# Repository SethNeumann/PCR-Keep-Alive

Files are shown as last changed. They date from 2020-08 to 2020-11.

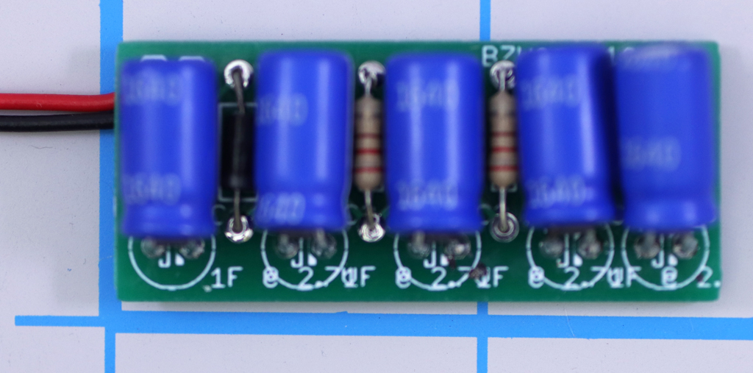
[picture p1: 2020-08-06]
PCR-Keep-Alive-Graphic.png

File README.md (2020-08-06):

# REPO NAME: EagleTemplate-new
## License: Creative Commons Attribution-NonCommercial-ShareAlike

A Keep-Alive is a large capacitor that will keep a DCC-equipped locomotive running for a few seconds in the absence of power to get over dirty track or a dead frog.  They can be used with most decoders.
Phil mentioned using a circuit found on the web instead of expensive offerings from decoder manufacturers
He started with something like https://www.dccguy.com/?tag=keep-alive by Dr. Larry Puckett (thanks Larry!)

We made some component changes:
Discharge Bypass Diode to Schottky 1N5819 (lower forward drop, less power)
Zener diode to 13V 1W 1N5243B 
Instead of 1/2W 100 ohm, used 2x220 ohm at 1/4W to save height and use a more available component

Note using a KA, other than the decoder manufacturers’, may void the decoder warranty

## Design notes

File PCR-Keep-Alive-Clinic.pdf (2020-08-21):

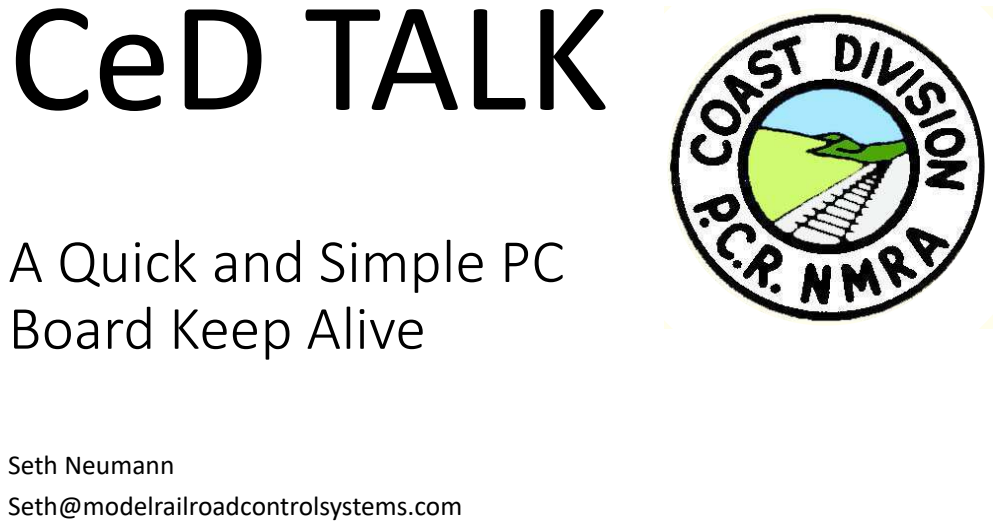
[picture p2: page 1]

A Quick and Simple PC
Board Keep Alive

Seth Neumann
Seth@modelrailroadcontrolsystems.com

# Why make a Keep-Alive board?

- A Keep-Alive is a large capacitor that will keep a DCC-equipped locomotive running for a few seconds in the absence of power to get over dirty track or a dead frog. They can be used with most decoders. • Phil mentioned using a circuit found on the web instead of expensive offerings from decoder manufacturers
- He started with something like https://www.dccguy.com/?tag=keep-alive by Dr. Larry Puckett (thanks Larry!)
- Note using a KA, other than the decoder manufacturers’, may void the decoder warranty
8/19/2020 | PCR Keep Alive for Coast Meet up August 8, 2020 | 2

# Pros and Cons of a KA like this

## - Good:

## - Inexpensive – about $8.00 in parts - Easy to assemble in various physical configurations

## - Not so Good:

## - Space wiring is hassle and is prone to coming apart at inopportune times (such as when the shell is tightened down)

## - Solution:

## - Use low cost circuit board to hold everything together

- Less flexibility in size but it can fit within an HO EMD shell.
8/19/2020 | PCR Keep Alive for Coast Meet up August 8, 2020 | 3

# My implementation

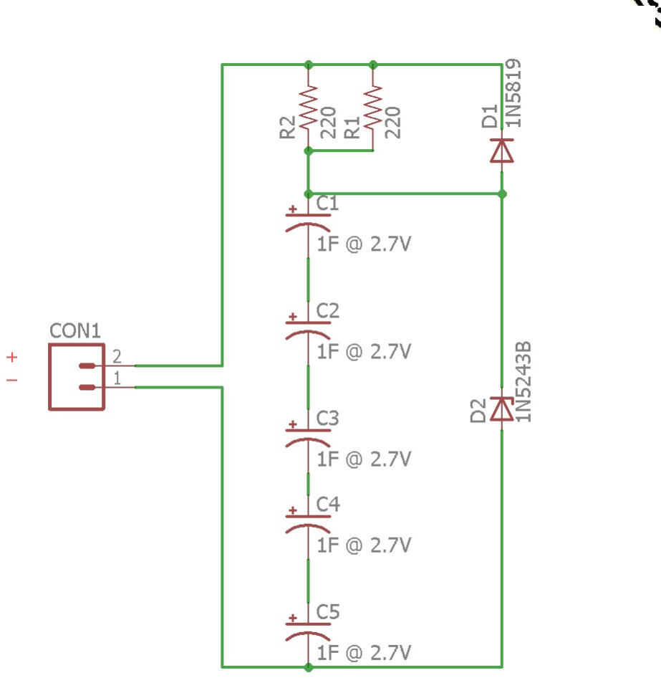
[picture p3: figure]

## - Discussed the application with DCC gurus “the Marks Brothers” - Made some component changes:

## - Discharge Bypass Diode to Schottky 1N5819 (lower forward drop, less power dissipated, so smaller) - Changed Zener diode to 13V 1W 1N5243B - smaller - I used 2x220 ohm at 1/4W instead of Instead of 1/2W 100 ohm to save height and use a more available component

# Prototype with Guy Cantwell

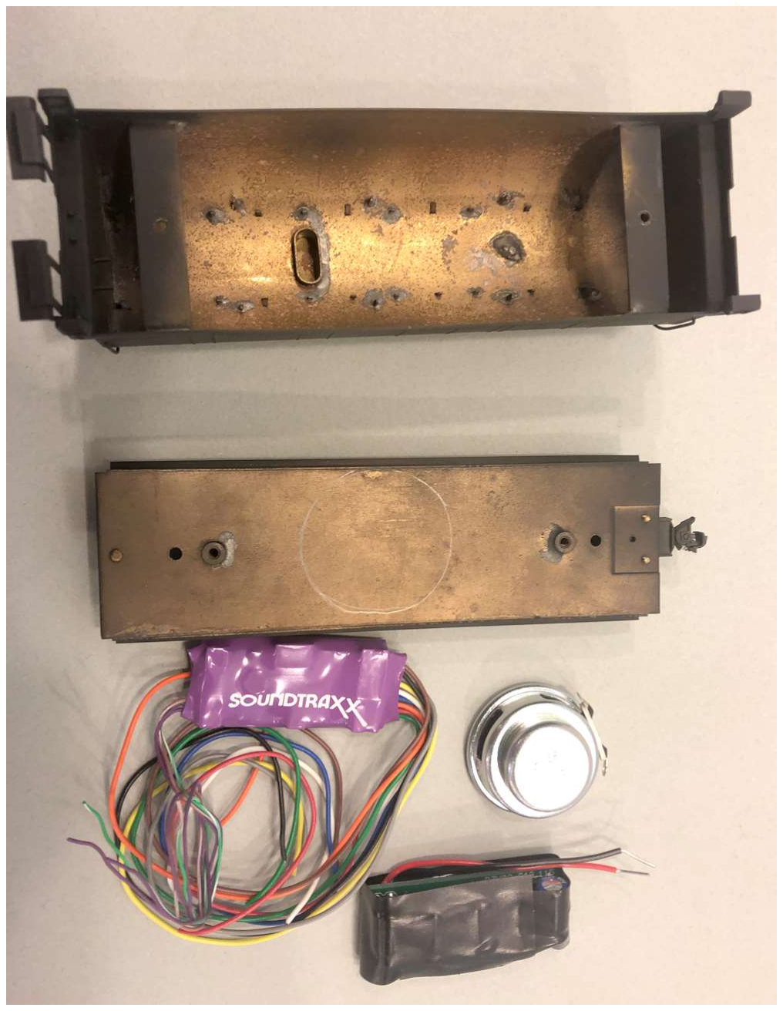
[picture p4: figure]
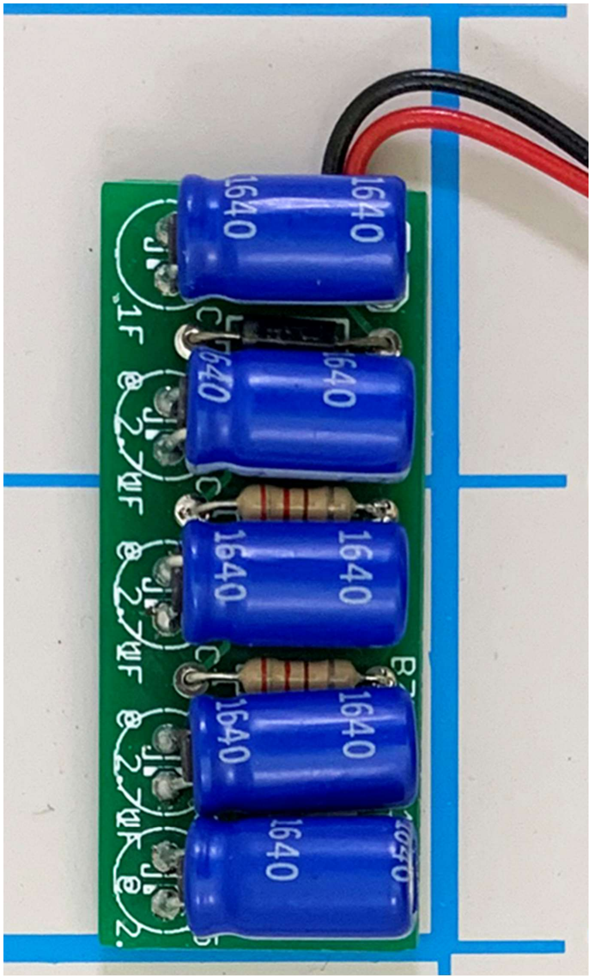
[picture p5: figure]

8/19/2020 | PCR Keep Alive for Coast Meet up August 8, 2020 | 5

.710” wide (17.5 mm)
1.650” long (42mm)
.400” thick (10 mm) –

# Bare Board

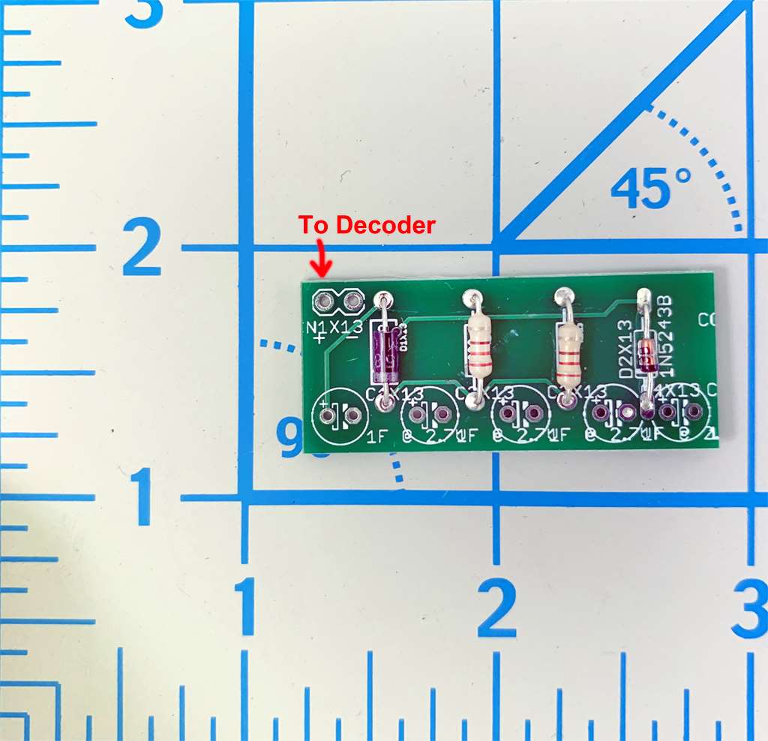
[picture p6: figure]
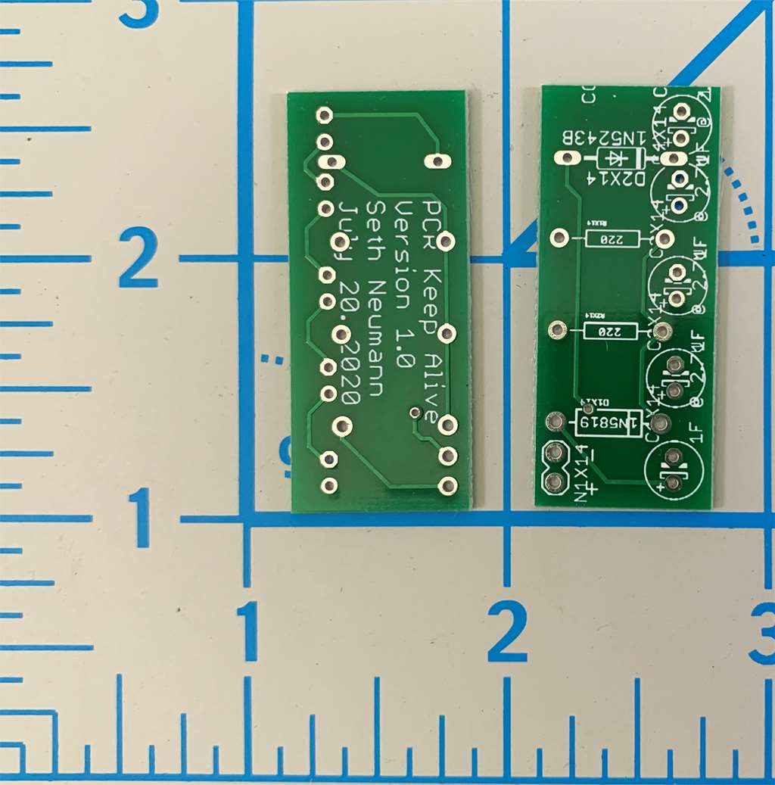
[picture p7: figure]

8/20/2020 | PCR Keep Alive for Coast Meet up August 8, 2020 | 6
Top and Bottom | Diodes and Resistor stuffed

# How does it fit?

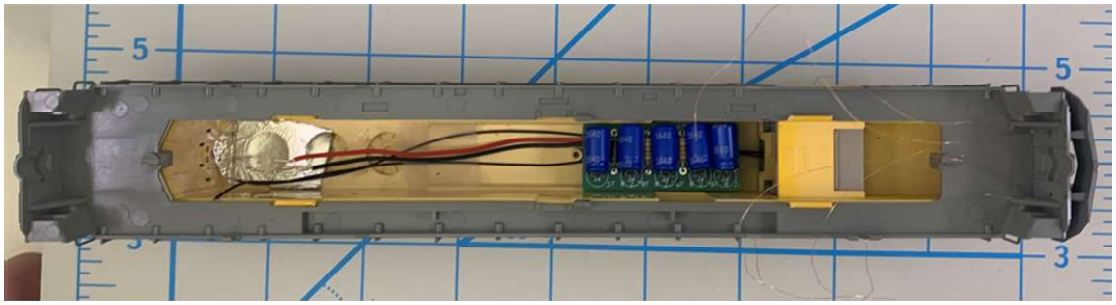
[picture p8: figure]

8/19/2020 | PCR Keep Alive for Coast Meet up August 8, 2020 | 7

## PCR-Keep-Alive in Athearn SD40-2 shell

# Guy Cantwell’s Steam Installation

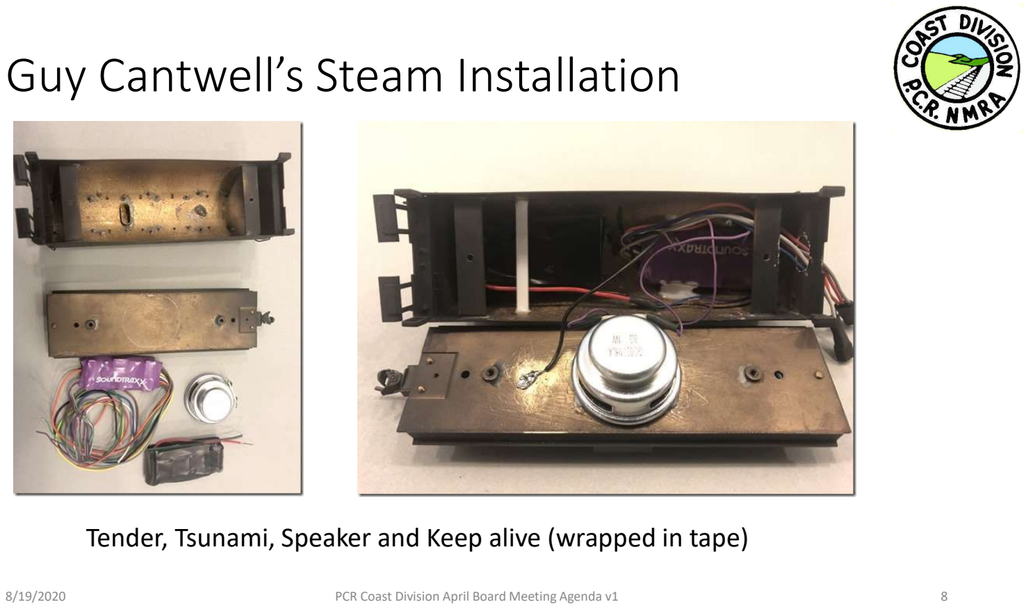
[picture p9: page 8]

8/19/2020 | PCR Coast Division April Board Meeting Agenda v1 | 8

## Tender, Tsunami, Speaker and Keep alive (wrapped in tape)

# Bill of Materials – 1 Unit

Quantity | Description | Digikey P/N | Unit | Ext’d
1 | Printed Circuit Board (panel of 10) | MRCS | $5.00 | $0.50
5 | AVX 1F 2.7V Super Capacitor | 478-10010-ND | $1.26 | $6.30
1 | 1N5819 1W Schottky Diode | 497-6610-1-ND | $0.30 | $0.30
1 | 1N5243B 13V 1W Zener | 1N5243BTRFSCT-ND | $0.14 | $0.14
2 | 220 ohm @ ¼ W resistor | CF14JT220RCT-ND | $0.10 | $0.20
Total for 1 unit | $7.44
8/19/2020 | 9

Plus sales tax, shipping, tariff surcharges etc, ~$20.00

You can purchase this BOM from Digikey at https://www.digikey.com/short/z5229d

# Bill of Materials – 10 Units

8/19/2020 | PCR Keep Alive for Coast Meet up August 8, 2020 | 10
Quantity | Description | Digikey P/N | Unit | Ext’d
10 | Printed Circuit Board (panel of 10) | MRCS | $5.00 | $5.00
50 | AVX 1F 2.7V Super Capacitor | 478-10010-ND | $1.09 | 54.60
10 | 1N5819 1W Schottky Diode | 497-6610-1-ND | $0.12 | $1.23
10 | 1N5243B 13V 1W Zener | 1N5243BTRFSCT-ND | $0.25 | $2.47
25 | 220 ohm @ ¼ W resistor | CF14JT220RCT-ND | $0.03 | $0.70
Total for 10 units | $64.00

Plus sales tax, shipping, tariff surcharges etc. ~ $13.00

You can purchase this BOM from Digikey at https://www.digikey.com/short/z52wpf

# Options to Purchase

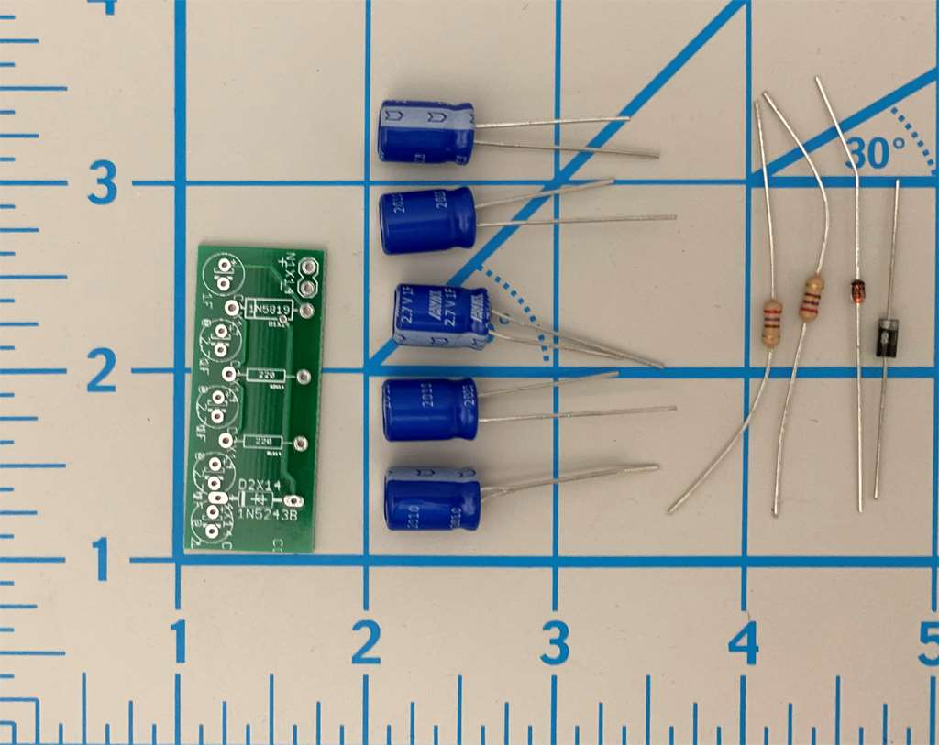
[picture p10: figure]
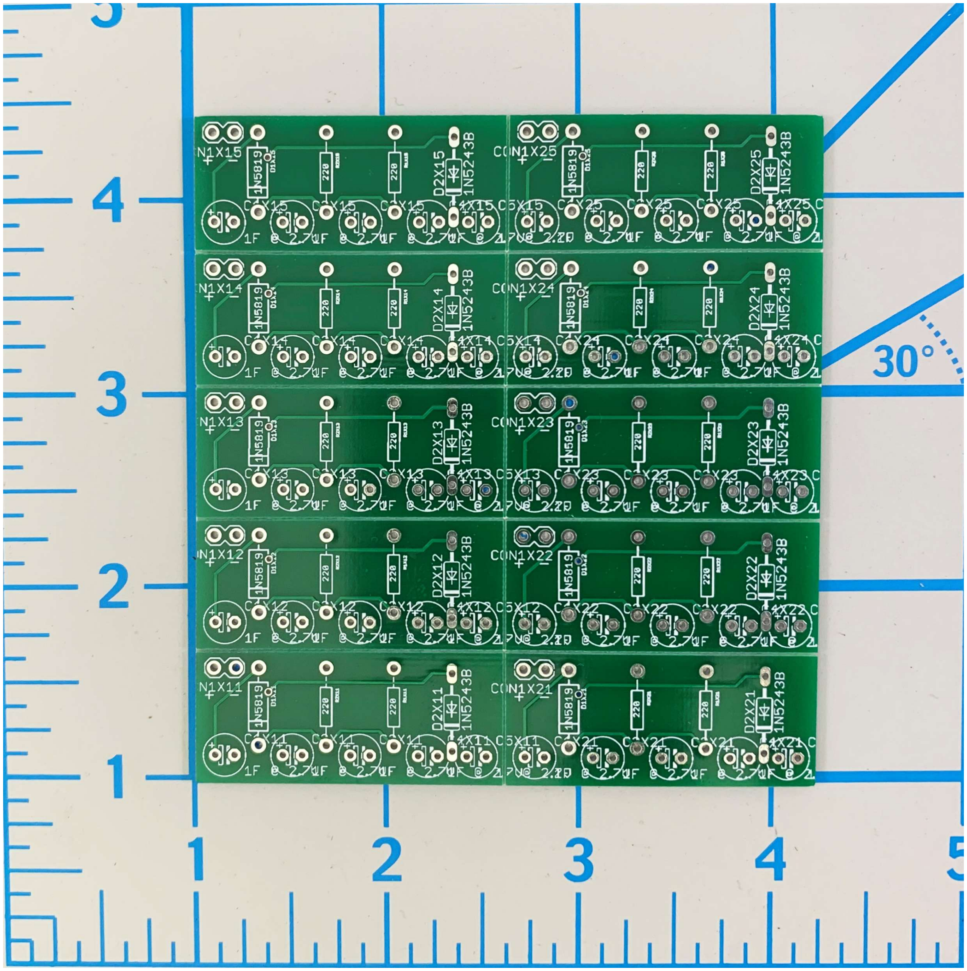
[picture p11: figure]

8/20/2020 | PCR Coast Division April Board Meeting Agenda v1 | 11
Panel of 10 - $5.00 | Kit for 1 - $9.95

# References and links

## - EAGLE CAD Files on my GitHub https://github.com/SethNeumann/PCR-Keep-Alive - MRCS Product Page for board https://www.modelrailroadcontrolsystems.com/pcr-keep-alive-panel-

of-10/

## - Larry Puckett’s Article like https://www.dccguy.com/?tag=keep-alive

8/19/2020 | PCR Keep Alive for Coast Meet up August 8, 2020 | 12

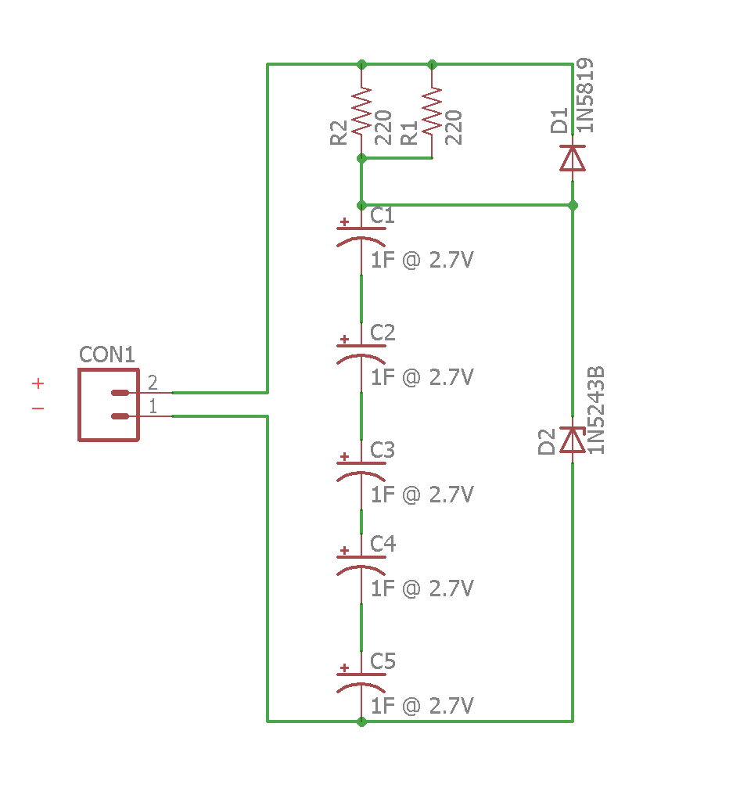
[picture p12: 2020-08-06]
PCR-KA-V2.png

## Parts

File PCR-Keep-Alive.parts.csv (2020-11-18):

# name | smd? | value | package | component | x | y | angle | YXAngle |  |  | Vendor | Part | Unit | Leads
PCB |  |  |  | PCR-Keep-Alive |  |  |  |  |  |  |  |  | 0.10
C1 | PTH | 1F @ 2.7V | E2 | 6-May | 1f @ 2.7v-e2 | 6-May | 0 | 0 | 0 | 90 | Digikey | ?SCCR12B105PRB | 1.26 | 2
C2 | PTH | 1F @ 2.7V | E2 | 6-May | 1f @ 2.7v-e2 | 6-May | 0 | 0 | 0 | 90 | Digikey | ?SCCR12B105PRB | 1.26
C3 | PTH | 1F @ 2.7V | E2 | 6-May | 1f @ 2.7v-e2 | 6-May | 0 | 0 | 0 | 90 | Digikey | ?SCCR12B105PRB | 1.26
C4 | PTH | 1F @ 2.7V | E2 | 6-May | 1f @ 2.7v-e2 | 6-May | 0 | 0 | 0 | 90 | Digikey | ?SCCR12B105PRB | 1.26
C5 | PTH | 1F @ 2.7V | E2 | 6-May | 1f @ 2.7v-e2 | 6-May | 0 | 0 | 0 | 90 | Digikey | ?SCCR12B105PRB | 1.26
CON1 | PTH |  | 1X02_LOCK | -1x02_lock | 0 | 0 | 180 | -90
D1 | PTH | 1N5819 | DIODE-1N4001 | 1n5819-diode-1n4001 | 0 | 0 | 90 | 0 |  |  | Digikey | 497-6610-1-ND | 0.21
D2 | PTH | 1N5243B | DO35Z10 | 1n5243b-do35z10 | 0 | 0 | 90 | 0 |  |  | Digikey | 1N5243BTRFSTR-ND | 0.13
R1 | PTH | 220 | AXIAL-0.4-RES | 220 -axial-0.4-res | 0 | 0 | 270 | 180 |  |  | Any |  | 0.04
R2 | PTH | 220 | AXIAL-0.4-RES | 220 -axial-0.4-res | 0 | 0 | 270 | 180 |  |  |  |  | 0.04
 |  |  |  |  |  |  |  |  |  |  |  |  | $6.82

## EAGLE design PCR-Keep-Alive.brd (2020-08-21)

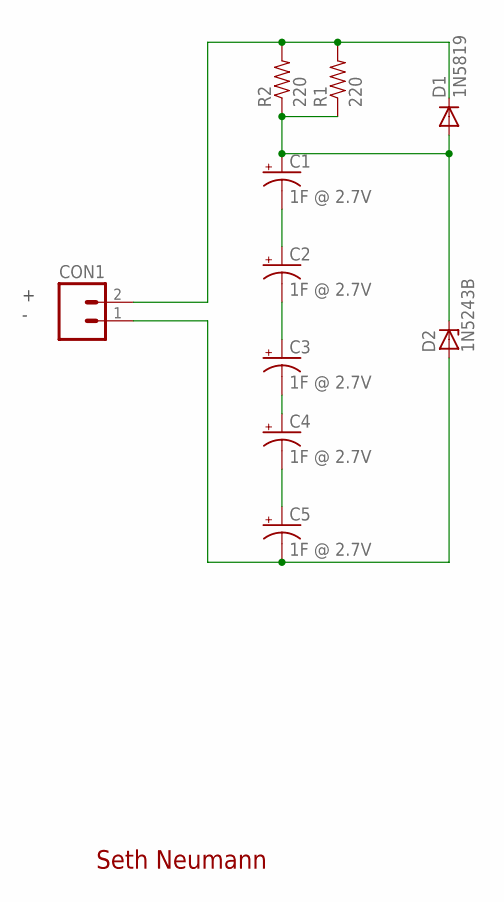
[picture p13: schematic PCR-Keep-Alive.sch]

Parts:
C1, C2, C3, C4, C5: 1F @ 2.7V; E2,5-6
CON1: CONNECTOR-M021X02-LOCK; 1X02_LOCK
D1: 1N5819; DIODE-1N4001
D2: 1N5243B; DO35Z10
R1, R2: 220; AXIAL-0.4-RES

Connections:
unnamed: C1.-, C2.+
unnamed: C2.-, C3.+
unnamed: C3.-, C4.+
unnamed: C4.-, C5.+
unnamed: C1.+, D1.A, D2.C, R1.P$1 (1), R2.P$1 (1)
NEG: C5.-, CON1.1 (A), D2.A
POS: CON1.2 (B), D1.C, R1.P$2 (2), R2.P$2 (2)

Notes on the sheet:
Seth Neumann
+ -

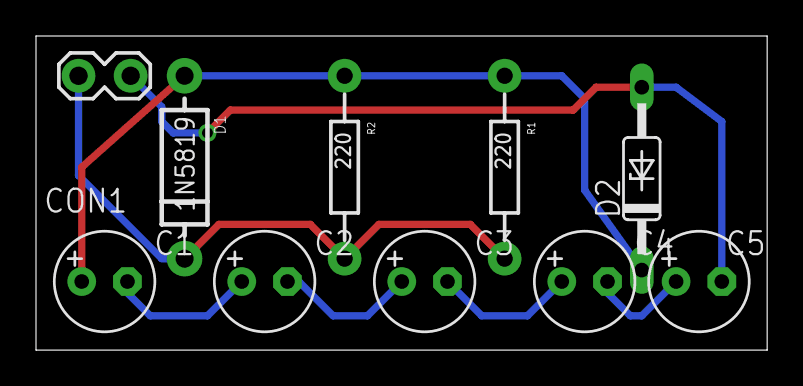
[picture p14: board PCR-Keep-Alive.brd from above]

Board: 2 copper layers, 40.6 x 17.4 mm, 10 parts (0 on the bottom side), 7 nets.

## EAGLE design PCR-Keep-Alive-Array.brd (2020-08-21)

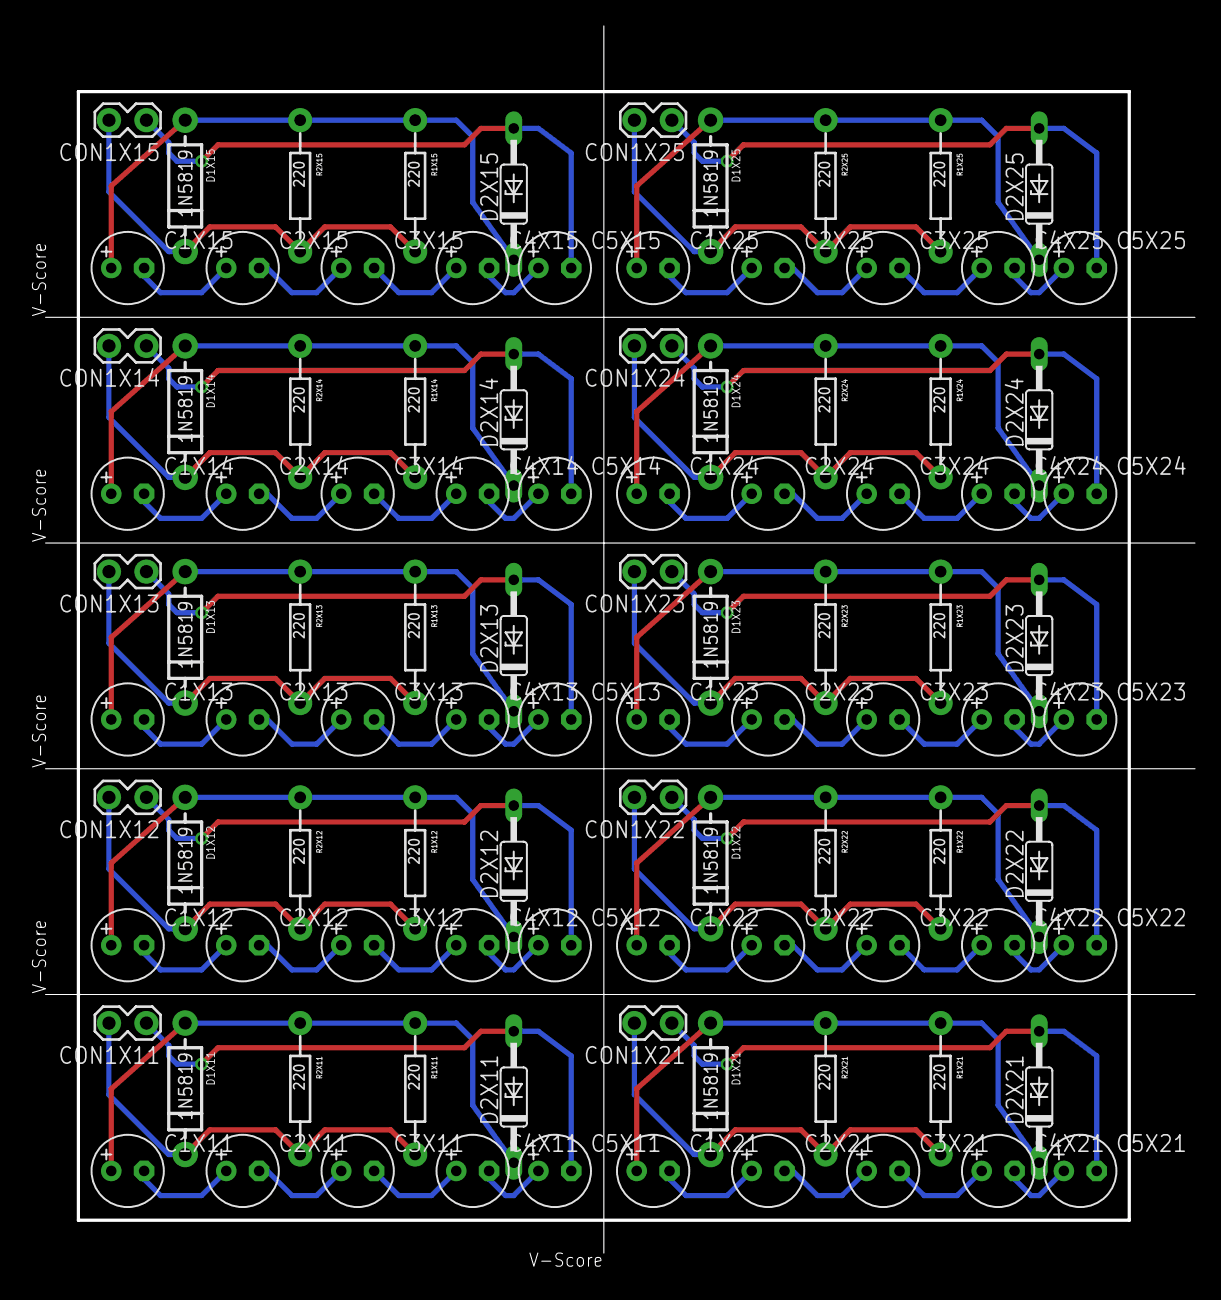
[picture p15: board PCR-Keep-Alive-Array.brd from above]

Board: 2 copper layers, 88.9 x 94.9 mm, 100 parts (0 on the bottom side), 70 nets.

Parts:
C1X11, C1X12, C1X13, C1X14, C1X15, C1X21, C1X22, C1X23, C1X24, C1X25, C2X11, C2X12, C2X13, C2X14, C2X15, C2X21, C2X22, C2X23, C2X24, C2X25, C3X11, C3X12, C3X13, C3X14, C3X15, C3X21, C3X22, C3X23, C3X24, C3X25, C4X11, C4X12, C4X13, C4X14, C4X15, C4X21, C4X22, C4X23, C4X24, C4X25, C5X11, C5X12, C5X13, C5X14, C5X15, C5X21, C5X22, C5X23, C5X24, C5X25: 1F @ 2.7V; E2,5-6
CON1X11, CON1X12, CON1X13, CON1X14, CON1X15, CON1X21, CON1X22, CON1X23, CON1X24, CON1X25: 1X02_LOCK
D1X11, D1X12, D1X13, D1X14, D1X15, D1X21, D1X22, D1X23, D1X24, D1X25: 1N5819; DIODE-1N4001
D2X11, D2X12, D2X13, D2X14, D2X15, D2X21, D2X22, D2X23, D2X24, D2X25: 1N5243B; DO35Z10
R1X11, R1X12, R1X13, R1X14, R1X15, R1X21, R1X22, R1X23, R1X24, R1X25, R2X11, R2X12, R2X13, R2X14, R2X15, R2X21, R2X22, R2X23, R2X24, R2X25: 220; AXIAL-0.4-RES

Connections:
unnamed: C1X11.-, C2X11.+
unnamed: C1X12.-, C2X12.+
unnamed: C1X13.-, C2X13.+
unnamed: C1X14.-, C2X14.+
unnamed: C1X15.-, C2X15.+
unnamed: C1X21.-, C2X21.+
unnamed: C1X22.-, C2X22.+
unnamed: C1X23.-, C2X23.+
unnamed: C1X24.-, C2X24.+
unnamed: C1X25.-, C2X25.+
unnamed: C2X11.-, C3X11.+
unnamed: C2X12.-, C3X12.+
unnamed: C2X13.-, C3X13.+
unnamed: C2X14.-, C3X14.+
unnamed: C2X15.-, C3X15.+
unnamed: C2X21.-, C3X21.+
unnamed: C2X22.-, C3X22.+
unnamed: C2X23.-, C3X23.+
unnamed: C2X24.-, C3X24.+
unnamed: C2X25.-, C3X25.+
unnamed: C3X11.-, C4X11.+
unnamed: C3X12.-, C4X12.+
unnamed: C3X13.-, C4X13.+
unnamed: C3X14.-, C4X14.+
unnamed: C3X15.-, C4X15.+
unnamed: C3X21.-, C4X21.+
unnamed: C3X22.-, C4X22.+
unnamed: C3X23.-, C4X23.+
unnamed: C3X24.-, C4X24.+
unnamed: C3X25.-, C4X25.+
unnamed: C4X11.-, C5X11.+
unnamed: C4X12.-, C5X12.+
unnamed: C4X13.-, C5X13.+
unnamed: C4X14.-, C5X14.+
unnamed: C4X15.-, C5X15.+
unnamed: C4X21.-, C5X21.+
unnamed: C4X22.-, C5X22.+
unnamed: C4X23.-, C5X23.+
unnamed: C4X24.-, C5X24.+
unnamed: C4X25.-, C5X25.+
unnamed: C1X11.+, D1X11.A, D2X11.C, R1X11.P$1, R2X11.P$1
unnamed: C1X12.+, D1X12.A, D2X12.C, R1X12.P$1, R2X12.P$1
unnamed: C1X13.+, D1X13.A, D2X13.C, R1X13.P$1, R2X13.P$1
unnamed: C1X14.+, D1X14.A, D2X14.C, R1X14.P$1, R2X14.P$1
unnamed: C1X15.+, D1X15.A, D2X15.C, R1X15.P$1, R2X15.P$1
unnamed: C1X21.+, D1X21.A, D2X21.C, R1X21.P$1, R2X21.P$1
unnamed: C1X22.+, D1X22.A, D2X22.C, R1X22.P$1, R2X22.P$1
unnamed: C1X23.+, D1X23.A, D2X23.C, R1X23.P$1, R2X23.P$1
unnamed: C1X24.+, D1X24.A, D2X24.C, R1X24.P$1, R2X24.P$1
unnamed: C1X25.+, D1X25.A, D2X25.C, R1X25.P$1, R2X25.P$1
NEGX11: C5X11.-, CON1X11.1, D2X11.A
NEGX12: C5X12.-, CON1X12.1, D2X12.A
NEGX13: C5X13.-, CON1X13.1, D2X13.A
NEGX14: C5X14.-, CON1X14.1, D2X14.A
NEGX15: C5X15.-, CON1X15.1, D2X15.A
NEGX21: C5X21.-, CON1X21.1, D2X21.A
NEGX22: C5X22.-, CON1X22.1, D2X22.A
NEGX23: C5X23.-, CON1X23.1, D2X23.A
NEGX24: C5X24.-, CON1X24.1, D2X24.A
NEGX25: C5X25.-, CON1X25.1, D2X25.A
POSX11: CON1X11.2, D1X11.C, R1X11.P$2, R2X11.P$2
POSX12: CON1X12.2, D1X12.C, R1X12.P$2, R2X12.P$2
POSX13: CON1X13.2, D1X13.C, R1X13.P$2, R2X13.P$2
POSX14: CON1X14.2, D1X14.C, R1X14.P$2, R2X14.P$2
POSX15: CON1X15.2, D1X15.C, R1X15.P$2, R2X15.P$2
POSX21: CON1X21.2, D1X21.C, R1X21.P$2, R2X21.P$2
POSX22: CON1X22.2, D1X22.C, R1X22.P$2, R2X22.P$2
POSX23: CON1X23.2, D1X23.C, R1X23.P$2, R2X23.P$2
POSX24: CON1X24.2, D1X24.C, R1X24.P$2, R2X24.P$2
POSX25: CON1X25.2, D1X25.C, R1X25.P$2, R2X25.P$2

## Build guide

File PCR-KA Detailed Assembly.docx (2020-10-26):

# PCR Keep Alive – Assembly V 1.1

## 1.1. Bill of Materials

Name | value | package
PCB | | PCR-KA
C1 | 1F @ 2.7V | E2
C2 | 1F @ 2.7V | E2
C3 | 1F @ 2.7V | E2
C4 | 1F @ 2.7V | E2
C5 | 1F @ 2.7V | E2
D1 | 1N5819
D2 | 1N5243B | DO35Z10
R1 | 220 | AXIAL-0.4-RES
R2 | 220 | AXIAL-0.4-RES

## 1.2. Detailed Assembly

[ ] All of the components are through-hole technology with wire leads. A lead bender is a useful tool for forming the leads at 90 degrees for easy insertion into the pad holes. The general rule is installing the lowest components first, working towards components that are higher off the board. This enables you to support the low components as you solder them.

[ ] Resistors, Diodes

[ ] Install Resistors R1 and R2. Install the gold tolerance band towards the top (terminal wires side) for easier reading of values, this is not critical, just be consistent.

[ ] Install diodes D1, D2. Observe polarity – band as marked on the board

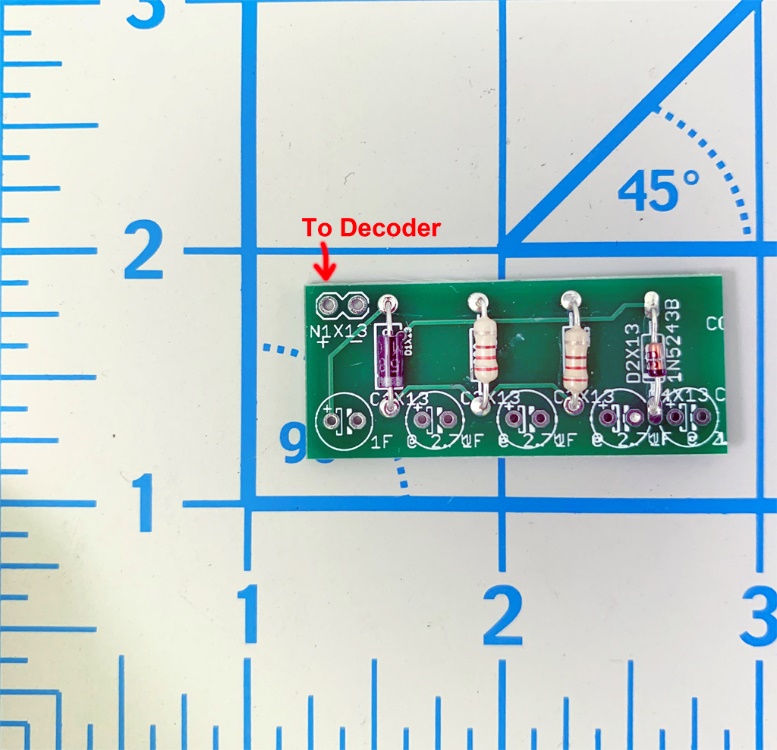
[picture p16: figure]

Figure 1- board with axial components (resistors and diodes) installed

[ ] Capacitors

[ ] install the capacitors, C1-C5 (they’re all the same), on their sides so they lay in between the resistors and diodes, This keeps the overall height lower for easier installation. Polarity is important! The long lead is the “+” side as marked on the board, the negative side is the side with the white band.

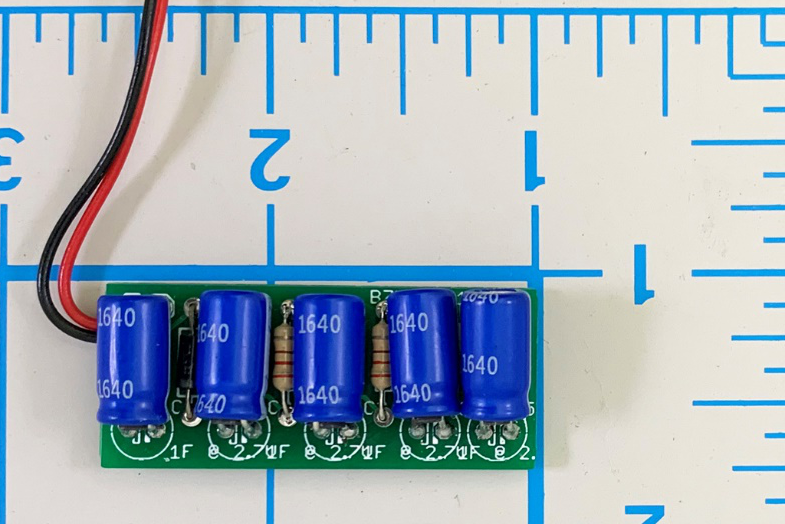
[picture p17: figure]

Figure 2 - PCR-KA with Capacitors Installed

[ ] Header

[ ] Install wires (or an 0.100 – 2.54 mm header if desired) from the bottom of the board, so that C1 will sit down properly. By convention, Red is positive and Black is negative.

Trim all leads and clean the board, I use 91% Isoproyl and a Q-Tip type swab.

Page 2 of 2 October 26, 2020

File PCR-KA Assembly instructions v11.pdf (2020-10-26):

Page 1 of 2 | October 26, 2020

# PCR Keep Alive – Assembly V 1.1

### 1.1.BILL OF MATERIALS

Name | value | package
PCB | | PCR-KA
C1 | 1F @ 2.7V | E2
C2 | 1F @ 2.7V | E2
C3 | 1F @ 2.7V | E2
C4 | 1F @ 2.7V | E2
C5 | 1F @ 2.7V | E2
D1 | 1N5819
D2 | 1N5243B | DO35Z10
R1 | 220 | AXIAL-0.4-RES
R2 | 220 | AXIAL-0.4-RES

### 1.2.DETAILED ASSEMBLY

[ ] All of the components are through-hole technology with wire leads. A lead bender is a useful tool for forming the leads at 90 degrees for easy insertion into the pad holes. The general rule is installing the lowest components first, working towards components that are higher off the board. This enables you to support the low components as you solder them.

[ ] Resistors, Diodes
[ ] Install Resistors R1 and R2. Install the gold tolerance band towards the top (terminal wires side) for easier reading of values, this is not critical, just be consistent.
[ ] Install diodes D1, D2. Observe polarity – band as marked on the board

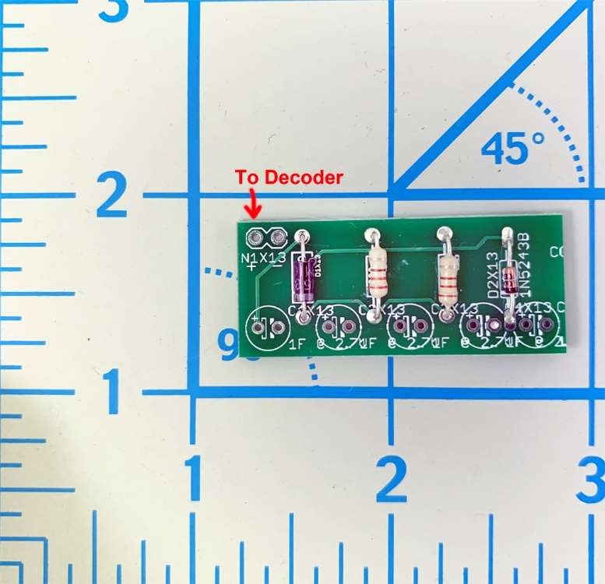
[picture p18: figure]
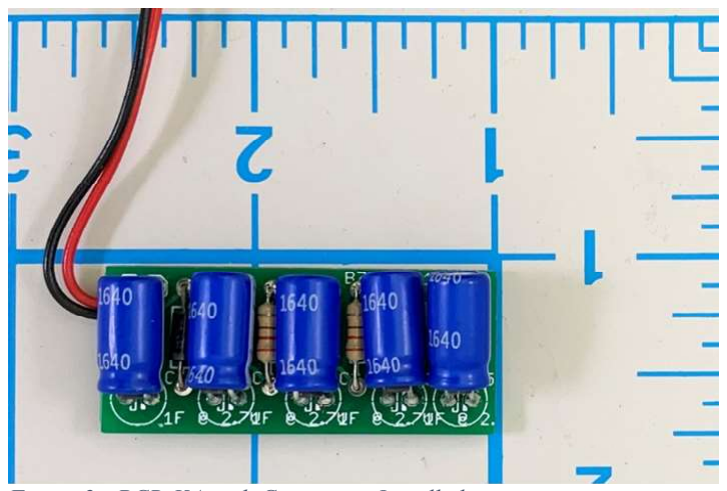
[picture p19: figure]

Page 2 of 2 | October 26, 2020

Figure 1- board with axial components (resistors and diodes) installed

[ ] Capacitors
[ ] install the capacitors, C1-C5 (they’re all the same), on their sides so they lay in between the resistors and diodes, This keeps the overall height lower for easier installation. Polarity is important! The long lead is the “+” side as marked on the board, the negative side is the side with the white band.

Figure 2 - PCR-KA with Capacitors Installed

[ ] Header
[ ] Install wires (or an 0.100 – 2.54 mm header if desired) from the bottom of the board, so that C1 will sit down properly. By convention, Red is positive and Black is negative.

Trim all leads and clean the board, I use 91% Isoproyl and a Q-Tip type swab.

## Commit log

2020-08-06 intial commit of local work
    PCR KA project
    [EagleTemplate-new.brd, EagleTemplate-new.sch, pcr-keep-alive r2.brd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]
2020-08-06 changed source names to conform
    housekeeping
    [PCR-Keep-Alive.brd, PCR-Keep-Alive.sch]
2020-08-21 updated clinic to reflect v1.1
    replaced SOT223 Zener with Axial
    [PCR-Keep-Alive-Array.brd, PCR-Keep-Alive.brd]
2020-10-26 added bill of materials
    added BOM to instructions
    [PCR-Keep-Alive.parts.csv]
2020-11-18 added test voltages to schematic drawing
    tets voltages to help check for bad capacitors or open circuits
    [PCR-Keep-Alive.parts.csv]
